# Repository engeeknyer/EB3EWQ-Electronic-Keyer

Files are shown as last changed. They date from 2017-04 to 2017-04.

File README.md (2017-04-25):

# EB3EWQ Electronic Keyer

The EB3EWQ Electrònic Keyer is a project espeally designed for Amateur Radio. Consist in a single board containing electronics and the keyer itsef. Using printed touch sensor, it provides a high speed keying, because there's no mechanical parts that affect the operator speed.

This project contents:

  - The source code for programming the ATtiny
  - The schematic diagram for eagle cad (.sch)
  - The PCB design for eagle cad (.brd)

Program is uploaded to ATtiny using Arduino IDE. Can be tested in Arduino UNO board.

TODO: 

  - Program a monitor output, already wired in the board.
  - Provide a way to program tone monitor output, adjusting at init state.

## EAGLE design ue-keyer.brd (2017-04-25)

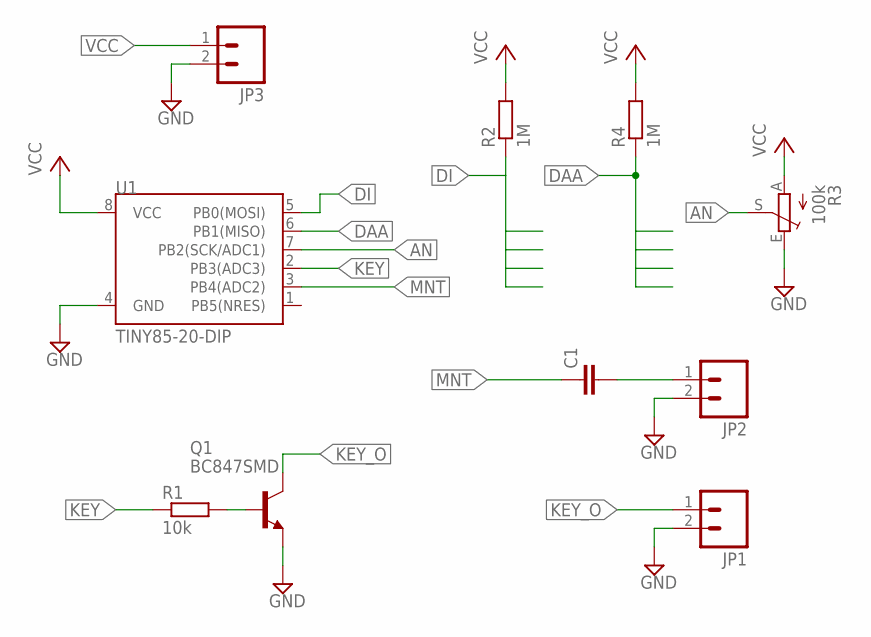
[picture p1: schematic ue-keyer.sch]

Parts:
C1: C-EUC1206; C1206
JP1, JP2, JP3: M02LOCK_LONGPADS; 1X02_LOCK_LONGPADS
Q1: BC847SMD; SOT23
R1: 10k; R0805
R2, R4: 1M; R0805
R3: 100k; ECP10S
U1: TINY85-20-DIP; DIP08

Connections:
AN: R3.S, U1.7 (PB2(SCK/ADC1))
DAA: R4.1, U1.6 (PB1(MISO))
DI: R2.1, U1.5 (PB0(MOSI))
GND: JP1.2, JP2.2, JP3.2, Q1.2 (E), R3.E, U1.4 (GND)
KEY: R1.1, U1.2 (PB3(ADC3))
KEY_O: JP1.1, Q1.3 (C)
MNT: C1.1, U1.3 (PB4(ADC2))
MNT_O: C1.2, JP2.1
unnamed: Q1.1 (B), R1.2
VCC: JP3.1, R2.2, R3.A, R4.2, U1.8 (VCC)

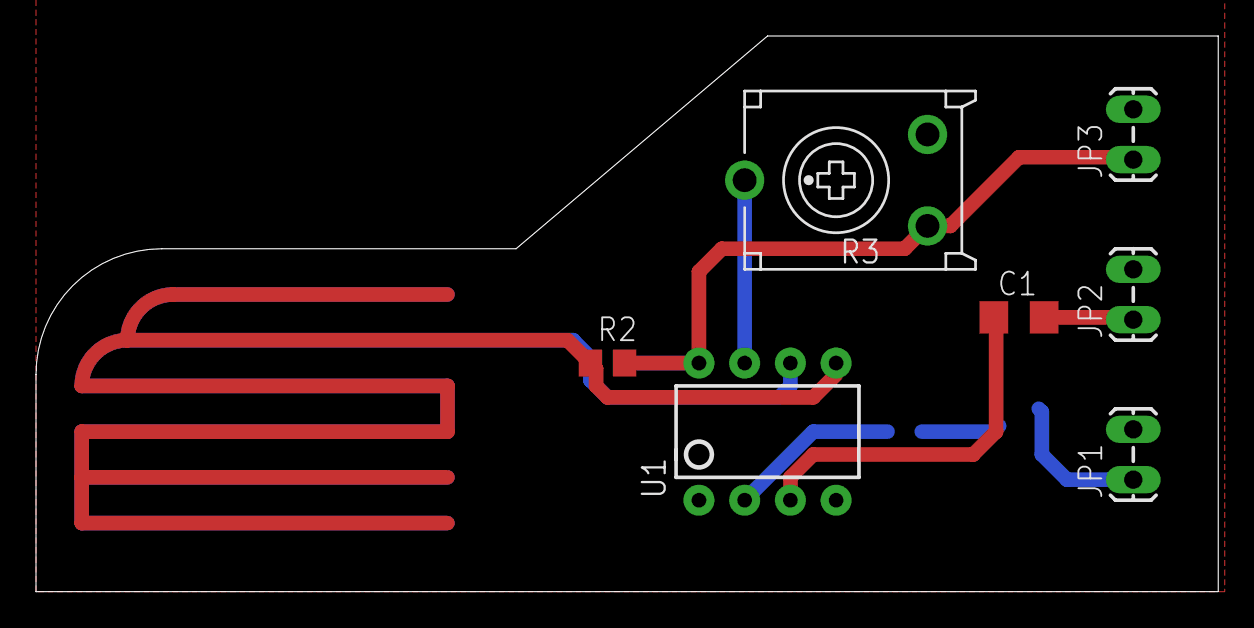
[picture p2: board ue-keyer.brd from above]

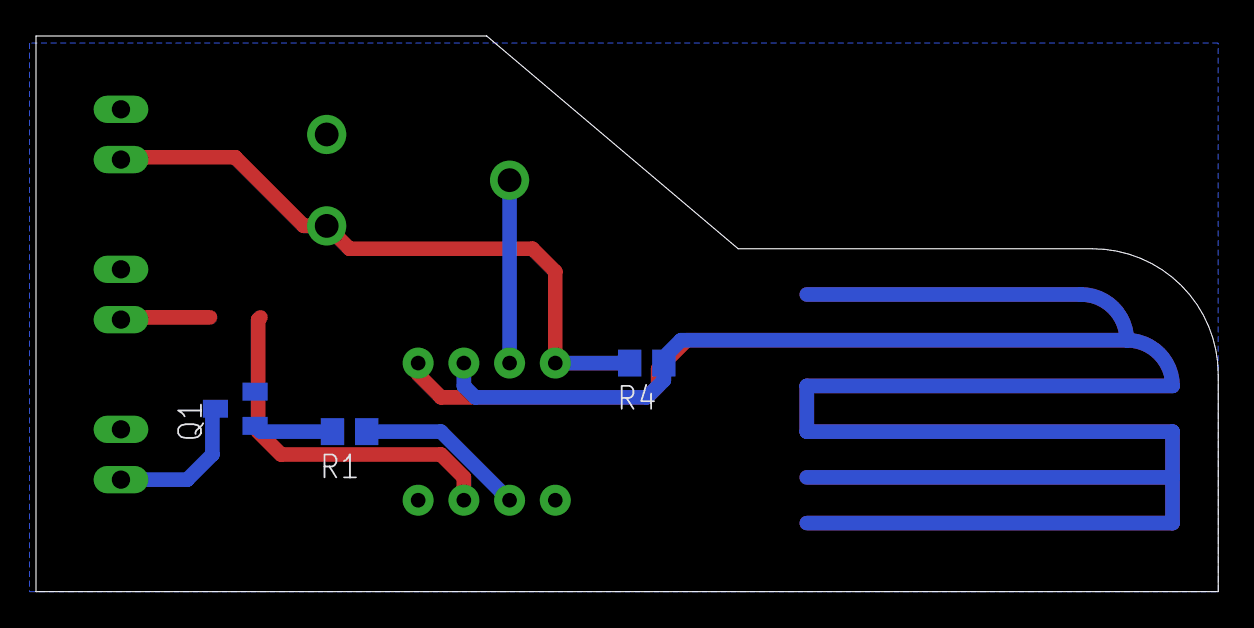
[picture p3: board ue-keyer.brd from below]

Board: 2 copper layers, 65.7 x 30.9 mm, 10 parts (3 on the bottom side), 10 nets.

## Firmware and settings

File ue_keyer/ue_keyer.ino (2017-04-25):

#define DI   0
#define DAA  1
#define MNT  4
#define KEY  3
#define AN   A1
#define PRESS  0
#define IDLE_K 0 


int value;

void setup() {
    pinMode(DI, INPUT);
    pinMode(DAA, INPUT);
    pinMode(KEY, OUTPUT);
    pinMode(MNT, OUTPUT);
    digitalWrite(KEY,IDLE_K);
    digitalWrite(MNT, 0);

    // Entering in setup mode....
    if (digitalRead(DI)==PRESS){
      setup1();
    } else
    if (digitalRead(DAA)==PRESS){
      setup2();
    }
    delay(100);
}

void loop() {
  value=analogRead(AN);
  value=map(value,0,1023,40,240);    //T=1200/WPM: 40ms=>30wpm, 240ms=> 5wpm
      if (digitalRead(DI)==PRESS){
      dit();
    } else
    if (digitalRead(DAA)==PRESS){
      dah();
    }
}



void setup1(){

  delay(100);
}

void setup2(){

  
  delay(100);
}

void dit(){
  digitalWrite(KEY,!IDLE_K);
  delay(value);
  digitalWrite(KEY, IDLE_K);
  delay(value);
}

void dah(){
  digitalWrite(KEY,!IDLE_K);
  delay(3*value);
  digitalWrite(KEY, IDLE_K);
  delay(value);
}

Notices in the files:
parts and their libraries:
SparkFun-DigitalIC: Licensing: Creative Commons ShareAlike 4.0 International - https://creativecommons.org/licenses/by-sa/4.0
